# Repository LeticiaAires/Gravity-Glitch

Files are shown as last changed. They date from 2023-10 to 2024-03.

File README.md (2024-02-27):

# Gravity Glitch



## Introduction

Welcome to Gravity Glitch, an innovative project created by 7th-semester engineering students from École Nationale Supérieure de l'Électronique et de ses Applications (ENSEA). This project serves as a platform for hands-on learning in practical electronics, software development, project management, and teamwork.

## Project Objective

Our primary goal is to develop an exciting game inspired by the popular Flappy Bird game, with a unique twist – an innovative controller. We've integrated an infrared sensor into the game, which measures the distance between the player's hand and the sensor. This inventive controller allows players to guide "Flappy" through the game, helping it navigate obstacles and accumulate points.

## Getting Started

To get started with the project, follow these steps:

1. Clone the repository to your local machine:

   ```bash
   git clone https://github.com/LeticiaAires/Gravity-Glitch.git
   ```

2. Ensure you have the required dependencies installed.

   [VSCode](https://code.visualstudio.com/download)
 
   [Python]( https://www.python.org/downloads/)
 
   [PIP](https://bootstrap.pypa.io/get-pip.py)

3. How to play ?
   
   - Run the "main.py" file 
   
   - Click on the "Play" button to choose your pseudo and choose your game mode !

4. To launch the game without installing all modules and packages on your machine, create a virtual environment.

   - Create the environment 'my_env' inside the project directory :
     
      ```bash
      python -m venv my_environment
      ```

   - Activate the environment :
     
      ```bash
      my_environment/bin/activate
      ```

   - Install the required dependencies :
   
      ```bash
      pip install -r requirements.txt
      ```

   - Run the Game.py file and play !

   - Deactivate the environment :
     
      ```bash
      deactivate
      ```

## Features

- Flappy Bird-inspired gameplay with a unique controller.
- Innovative use of an infrared sensor for hand tracking.
- Challenging obstacles and addictive gameplay.
- Project designed and implemented by talented engineering students.

## Documentation
Here is an explanation of the game's structure : 

The "main.py" file is the file to run to start the Game. Then, we come across a window called "MainMenu" displaying the menu of the game (with the settings, play, quit, credits and rules buttons). From there, we can : 
- go to the settings/rules/credits windows who are self explanatory
- quit the game
- go to the play window
  
If you choose to do the later, then you will come across a first window asking for your name (to associate your score with your pseudo). From there you can either go back to the menu or continue and go choose your game mode (History mode or alternative = a more complex version of the flappy bird).
After that, by clicking on continue and pressing the space bar, you can start playing !
You have a "pause" button in the bottom left corner where you can go to the settings, see the best scores, restart, resume or quit the game. 
  
For more detailed information about the project, you can refer to the code itself. We have included comprehensive comments and documentation within the codebase to help you understand how everything works.

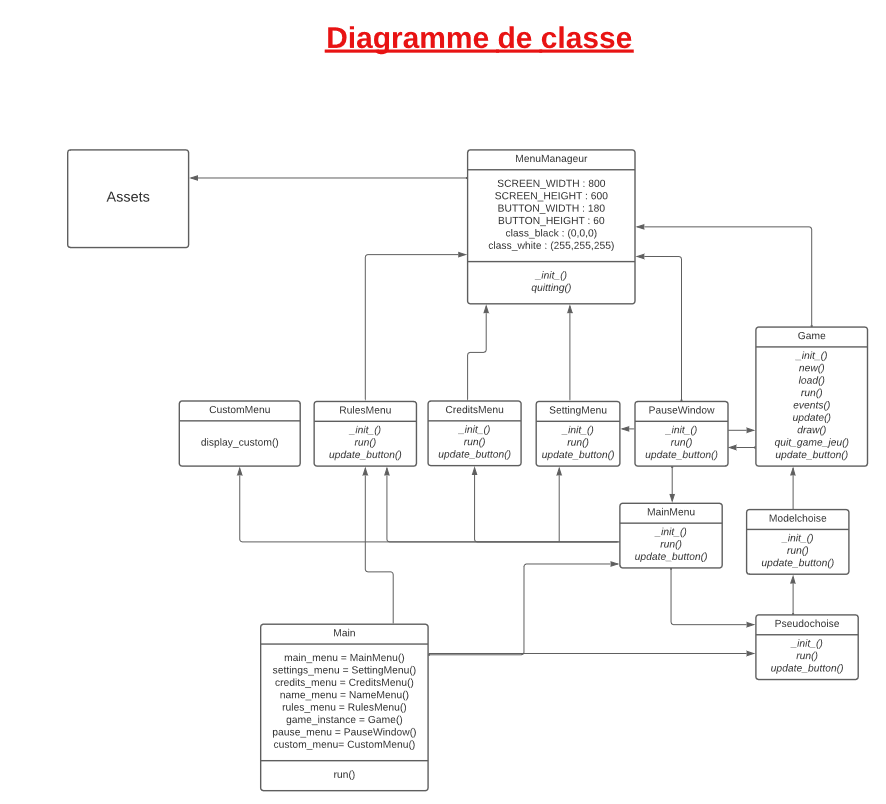
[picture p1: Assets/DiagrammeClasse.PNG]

## License

This project is licensed under the [MIT License](LICENSE.md).

## Acknowledgments

We would like to express our gratitude to our instructors, mentors, and everyone who supported us throughout this project. Your guidance and encouragement were invaluable in making this project a reality.

## Collaborators

<table>
  <tr>
    <td align="center">
      <a href="#">
        Foto Anthony
        <sub>
          <b>Anthony </b>
          </p>AnthonyDelille01     
        </sub>
      </a>
    </td>
    <td align="center">
      <a href="#">
        Foto Cassandre<br>
        <sub>
          <b>Cassandre   </b>
          </p>CassandreChandelier   
        </sub>
      </a>
      <td align="center">
      <a href="#">
        Foto Douay<br>
        <sub>
          <b>Douay Nicolas</b>
          </p>DBXYD
        </sub>
      </a>
    </td>
    <td align="center">
      <a href="#">
        Foto Letícia Aires<br>
        <sub>
          <b>Letícia Aires</b>
          </p>LeticiaAires
        </sub>
      </a>
    </td>
    <td align="center">
      <a href="#">
        Foto Mael<br>
        <sub>
          <b>Mael Doublet</b>
          </p>MaelDoublet
        </sub>
      </a>
      <td align="center">
      <a href="#">
        Foto Mantou<br>
        <sub>
          <b>Mantou</b>
          </p>Mansko09
        </sub>
      </a>
<td align="center">
      <a href="#">
        Foto Mathieu<br>
        <sub>
          <b>Mathieu Daubercies</b>
          </p>MathieuDaubercies
        </sub>
      </a>
      <td align="center">
      <a href="#">
        <br>
        <sub>
          <b>Solène</b>
          </p>salom0701
        </sub>
      </a>
      <td align="center">
      <a href="#">
        Foto Romain<br>
        <sub>
          <b>Romain</b>
          </p>Romain04G
        </sub>
      </a>
      <td align="center">
      <a href="#">
        Foto Zineb<br>
        <sub>
          <b>Zineb</b>
          </p>Ninevv
        </sub>
      </a>

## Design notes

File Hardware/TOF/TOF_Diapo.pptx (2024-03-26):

## TOF Process

Communicating with a TOF sensor

## Steps for TOF ranging

I. Pin configuration
II. USART communication
III. TOF ranging
IV. Getting the distance

## Pin configuration

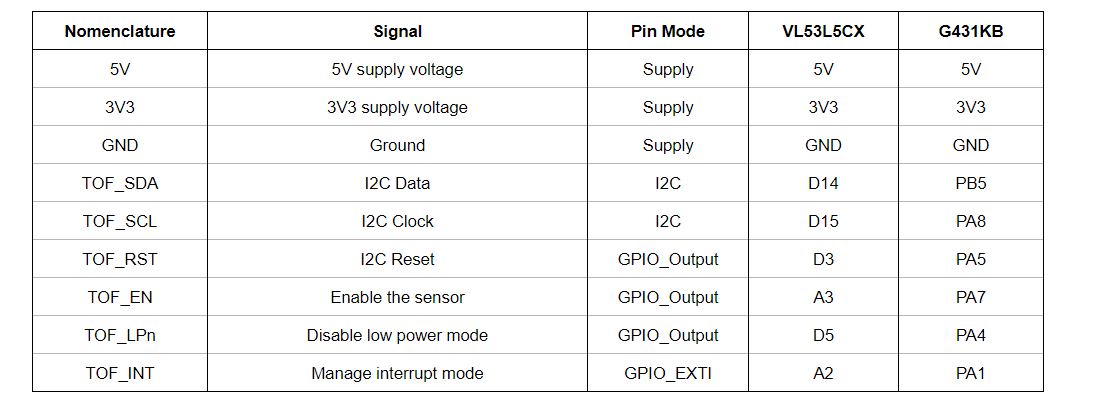
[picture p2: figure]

## Pin configuration

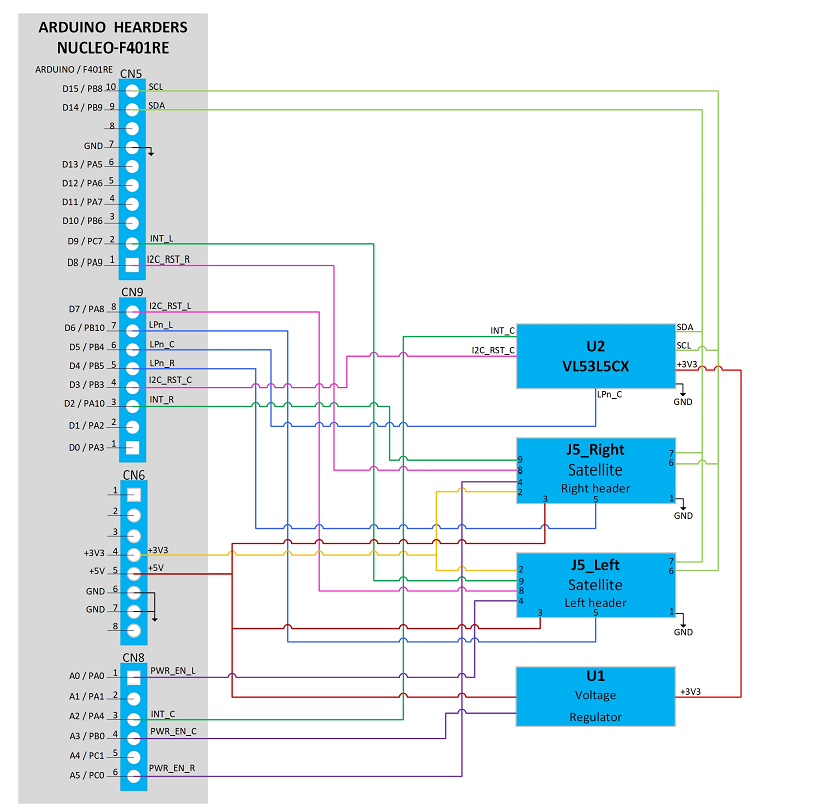
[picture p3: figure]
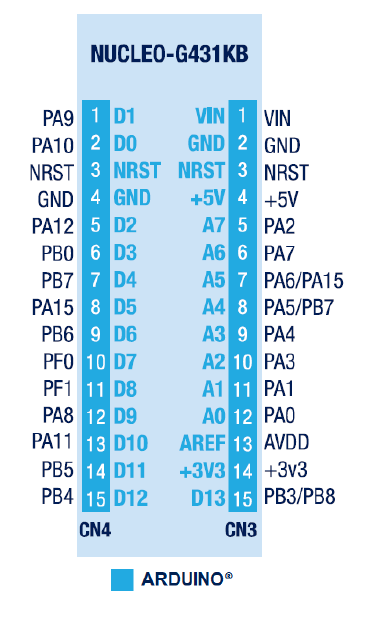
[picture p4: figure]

## Checking pin configuration

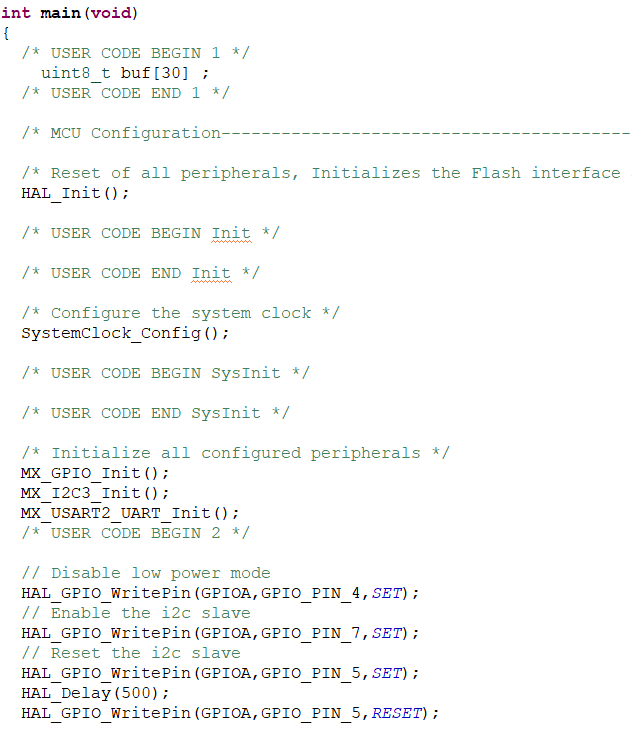
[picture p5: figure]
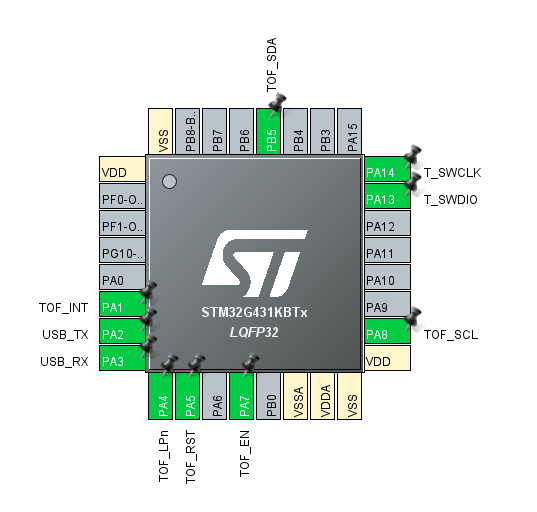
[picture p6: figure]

## Checking pin configuration

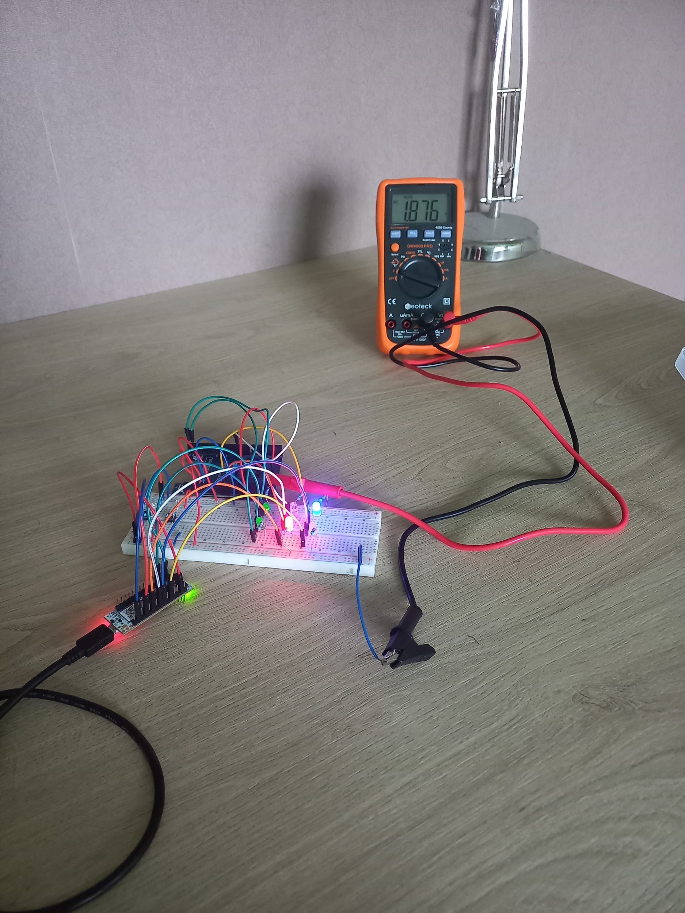
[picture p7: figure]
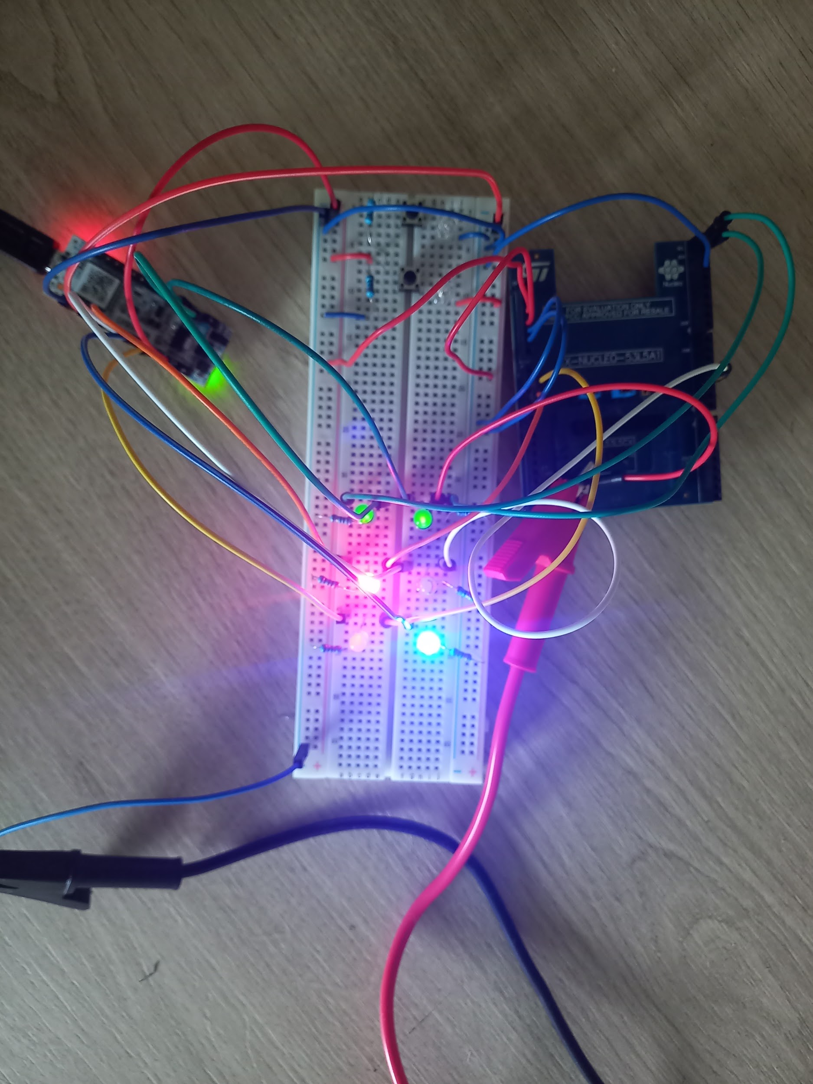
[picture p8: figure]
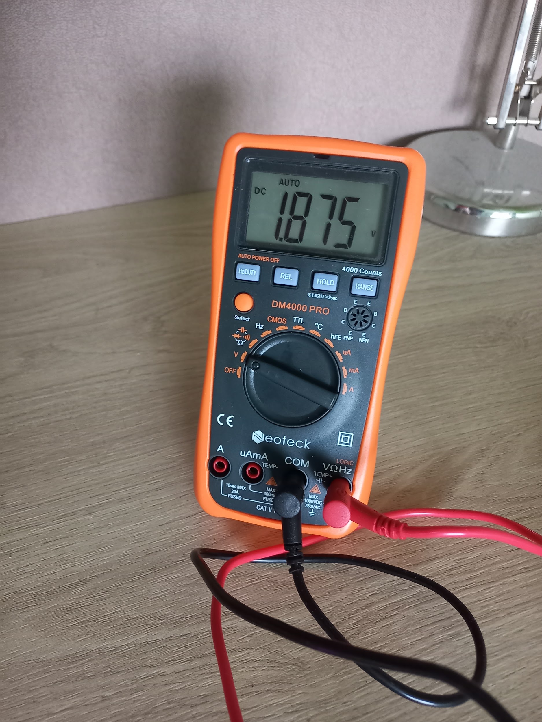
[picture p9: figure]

## USART communication

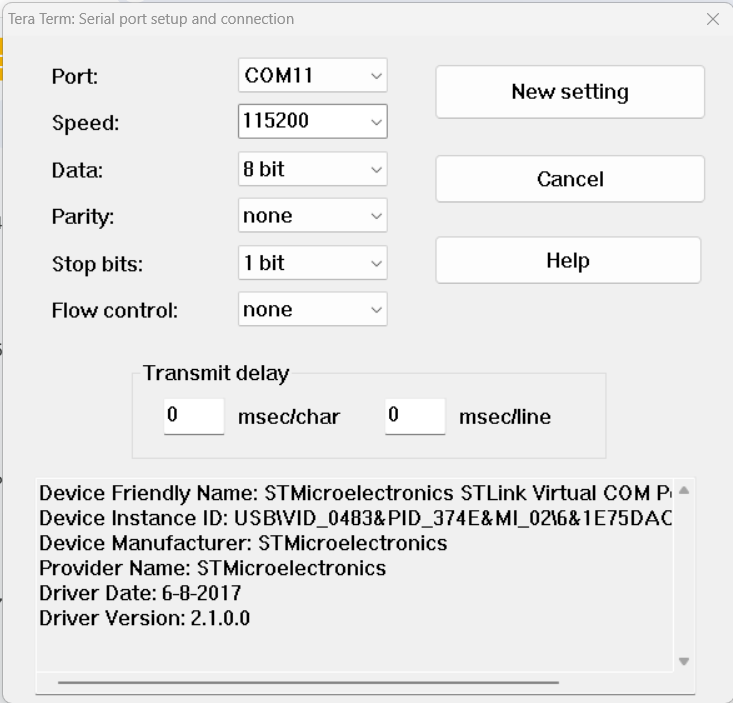
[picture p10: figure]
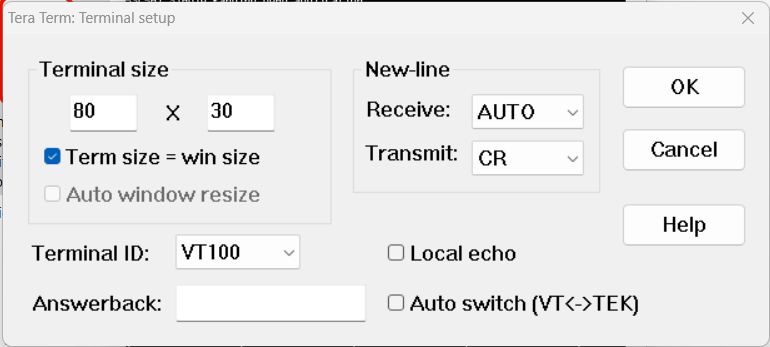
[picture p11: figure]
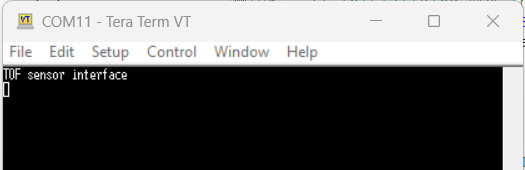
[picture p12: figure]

## USART communication

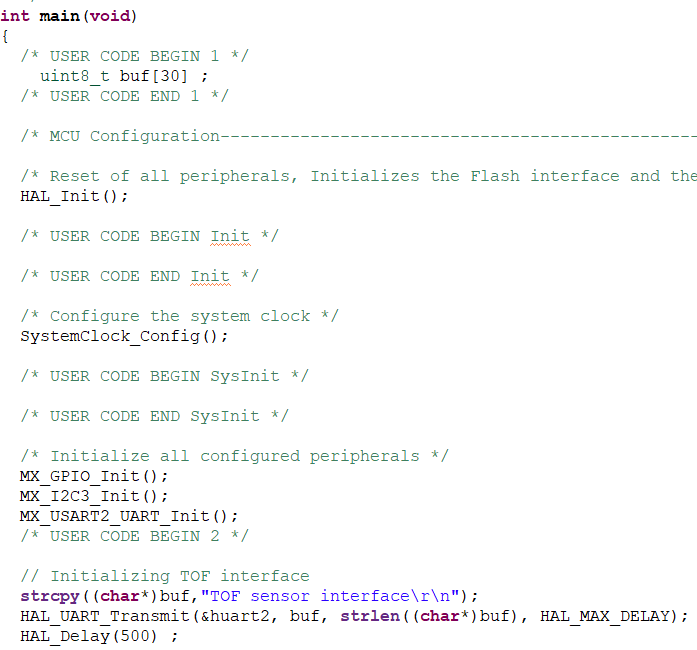
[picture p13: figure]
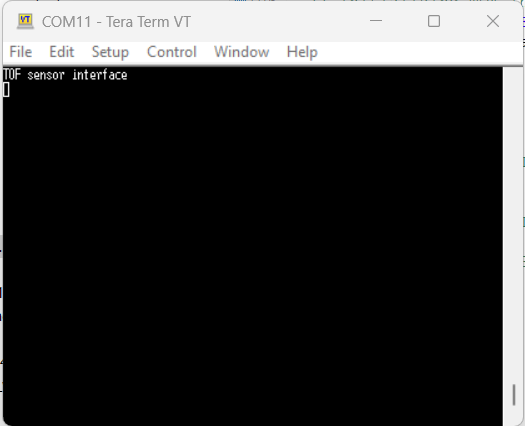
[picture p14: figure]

## TOF ranging

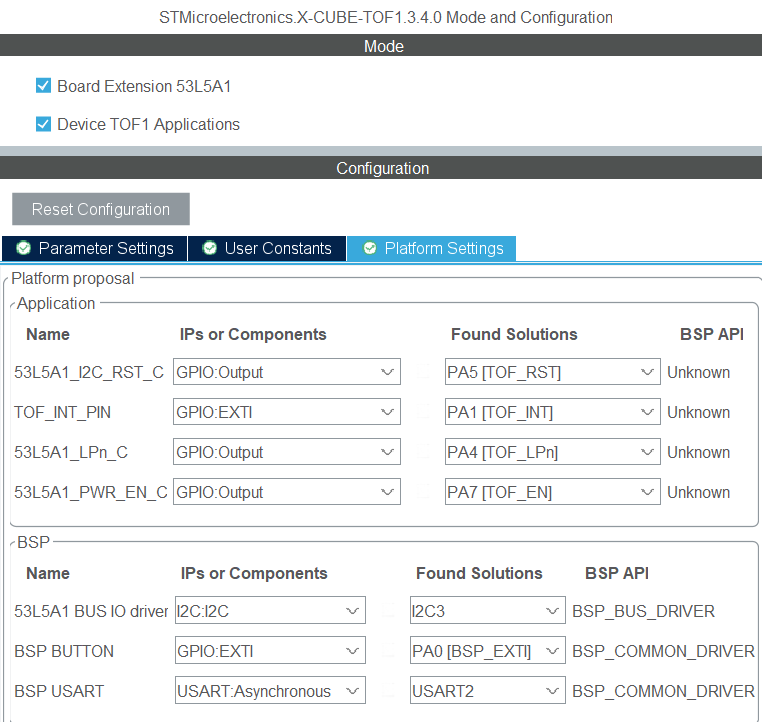
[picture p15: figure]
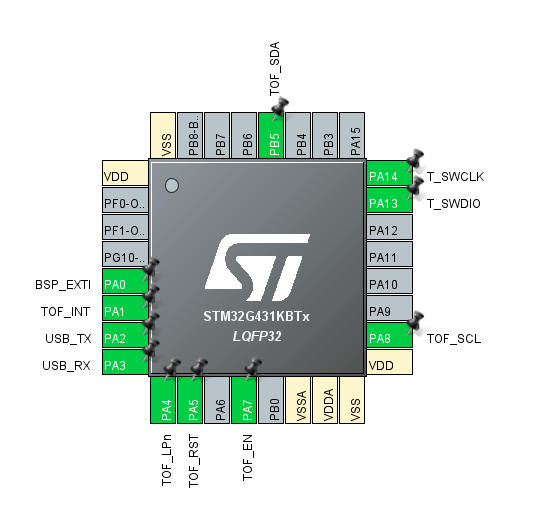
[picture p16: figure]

## TOF ranging

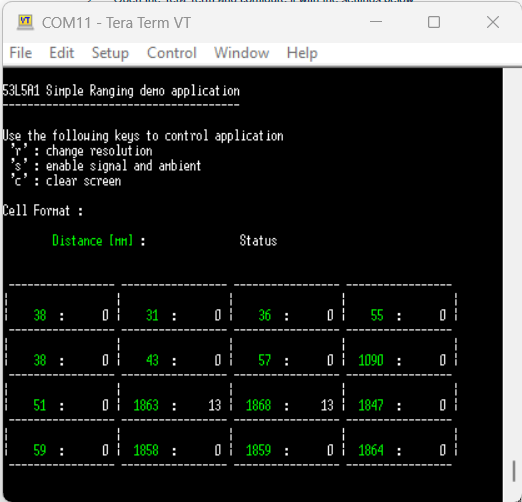
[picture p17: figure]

## Getting the distance

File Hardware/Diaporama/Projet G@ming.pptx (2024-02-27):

## Projet ~~G@ming~~ Gaming

Anthony Delille, Mathieu Daubercies, Nicolas Douay, Mael Doublet, Romain Gaillard

## Objectifs

- Faire un schéma global du système
- Connecter le TOF et la STM32
- Commencer le KiCad
- Se renseigner sur le bluetooth

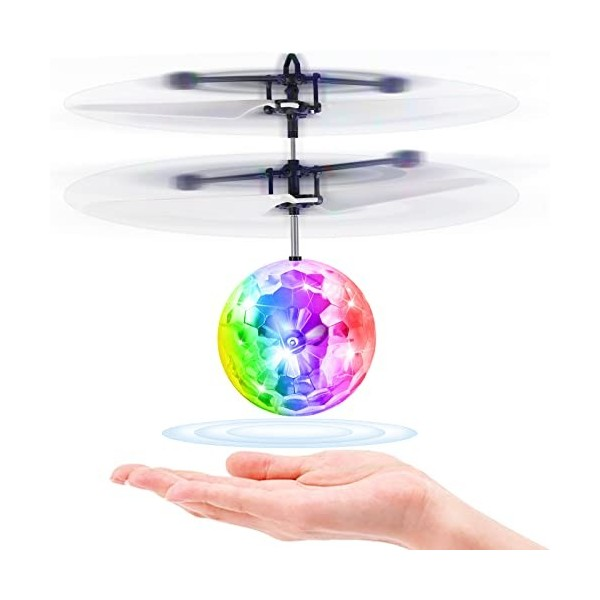
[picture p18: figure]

## Architecture générale

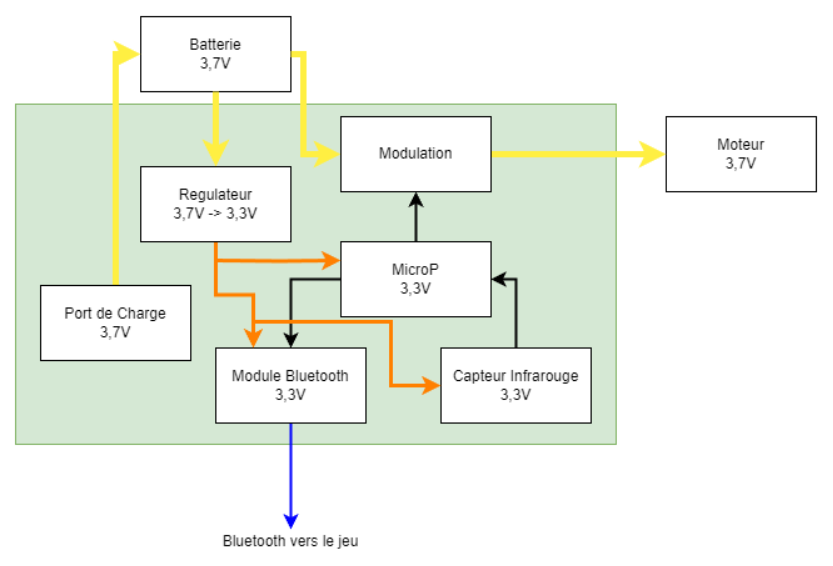
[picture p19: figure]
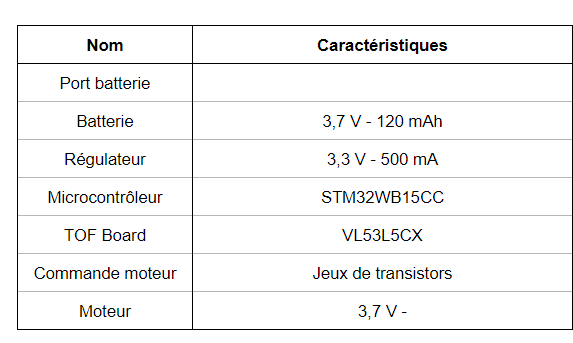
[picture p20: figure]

## Communication avec le TOF

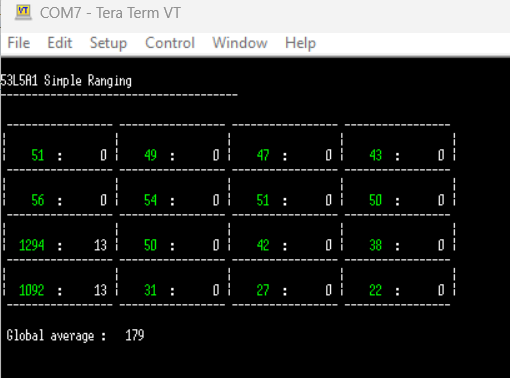
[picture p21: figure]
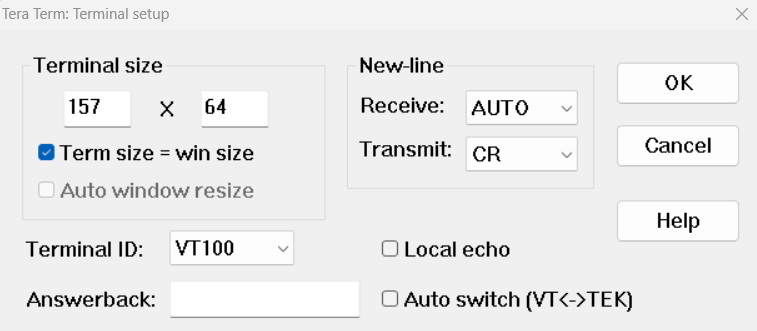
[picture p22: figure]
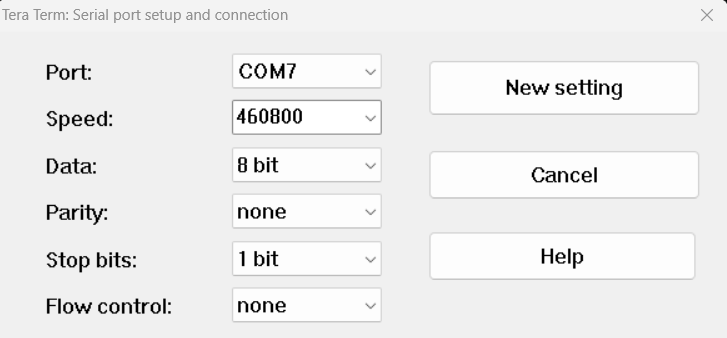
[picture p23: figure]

## Changement de carte

- Adaptation de la configuration de pins
- Création d’un nouveau projet :
  - Configuration IOC avec WB15CC
  - Erreurs dans la compilation du code

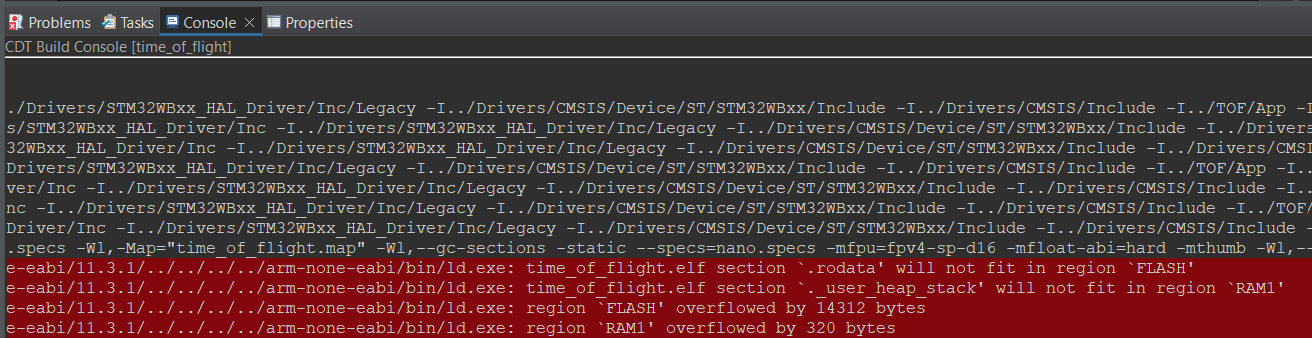
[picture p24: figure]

## Schematic du TOF

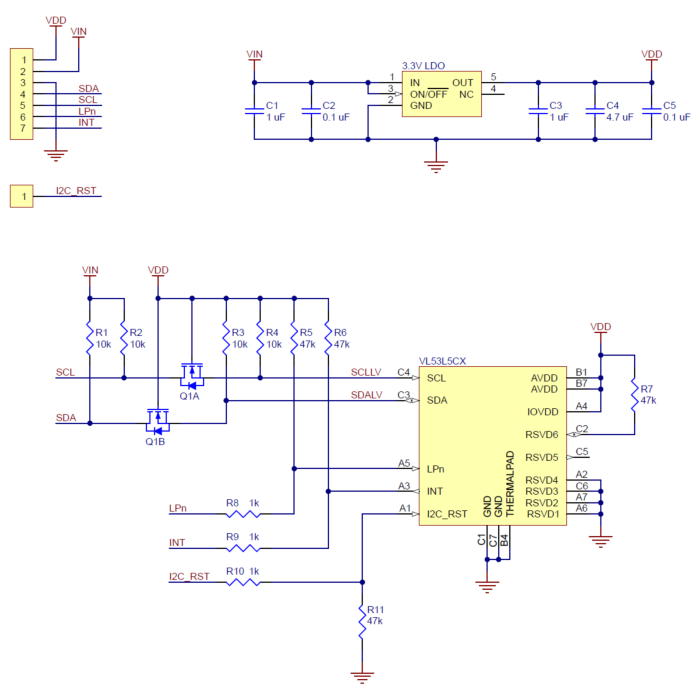
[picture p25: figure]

Régulateur de tension


TOF

## Schematic du TOF

VDD : 3.3 V
Régulateur de tension : VIN entre 2.8 V et 5.5 V


## Première piste pour le bluetooth

- Module
  - HC-05 / HC-06 : MAIS peut-être un peu grand: 35*16*12 mm
    - HC-05 : très courant / émetteur ou récepteur / fréquence d’émission réglable / fonctions AT
    - HC-06 : variante plus simple d’utilisation du HC-05 / fréquence d’émission réglable NON REGLABLE
    - blueNRG : de STM32 / beaucoup de docs / pas les fonctions AT
- Juste envoyer des données à l’ordinateur
  - configurer en mode émetteur
- Fonctions AT
  - permettent de paramétrer les caractéristiques du réseaux bluetooth: vitesse / nom / …
  - PAS TOUS les modules sont compatibles

## Et après ??

- Continuer la partie bluetooth
  - Choisir quelle module utilisé
  - trouver du code
- Régler le problème du changement de carte du TOF
- Continuer le Kicad

## Annexes

## Affichage de la moyenne


## Code de la moyenne


## Mémo pins TOF


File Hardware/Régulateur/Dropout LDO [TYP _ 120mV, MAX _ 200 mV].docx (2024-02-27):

Chute maximale de tension de 200 mV lorsque la tension de sortie est 100 mV en dessous de sa valeur minimale.

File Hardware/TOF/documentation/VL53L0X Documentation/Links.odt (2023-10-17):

LINKS

Programming I2C with STM32

https://wiki.st.com/stm32mcu/wiki/Getting_started_with_I2C

Programming I2C with Nucleo board and Time-of-Flight sensor :

https://www.youtube.com/watch?v=cvmQNTVJrzs

I2C in driver C :

https://www.youtube.com/watch?v=yZGWpDTbjdw

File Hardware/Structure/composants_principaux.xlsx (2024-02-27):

Composants principaux
Nom | Caractéristiques | Disponibilité | Datasheet
Port batterie |  | Fourni par le drône
Batterie | 3,7 V - 120 mAh | Fourni par le drône
Régulateur | 3,3 V - 500 mA | Commandé via Patricia | https://www.ti.com/lit/ds/symlink/lp3990.pdf?HQS=dis-mous-null-mousermode-dsf-pf-null-wwe&ts=1699970352925
Microcontrôleur | STM32WB15CC
TOF Board | VL53L5CX
Commande moteur | Jeux de transistors
Moteur | 3,7 V - | Fourni par le drône

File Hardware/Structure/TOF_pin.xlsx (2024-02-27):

TOF pin configuration
Nomenclature | Signal | Connecteur | Pin
VDD | 2,8 V out | not connected | not connected
VIN | 3,3 V in | CN6 | 3V3
GND | GND | GND | GND
SDA | I2C serial datas | CN5 | D14
SDL | I2C serial clock | CN5 | D15
XSHUT | Not enable pin | not connected | not connected
GPIO1 | Interrupt output pin | not connected | not connected

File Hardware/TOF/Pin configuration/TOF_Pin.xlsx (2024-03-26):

TOF pin configuration
Nomenclature | Signal | Pin Mode | VL53L5CX | G431KB
5V | 5V supply voltage | Supply | 5V | 5V
3V3 | 3V3 supply voltage | Supply | 3V3 | 3V3
GND | Ground | Supply | GND | GND
TOF_SDA | I2C Data | I2C | D14 | PB5
TOF_SCL | I2C Clock | I2C | D15 | PA8
TOF_RST | I2C Reset | GPIO_Output | D3 | PA5
TOF_EN | Enable the sensor | GPIO_Output | A3 | PA7
TOF_LPn | Disable low power mode | GPIO_Output | D5 | PA4
TOF_INT | Manage interrupt mode | GPIO_EXTI | A2 | PA1

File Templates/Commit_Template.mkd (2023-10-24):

## Commit

Commiting is the act of inserting your code adjustments into the main code, in which everyone is working.
In order for us to better understand each other's commits, they must be brief, descriptive and have a pattern.

### Principles:

#### Atomic commits
Commits must always be small and significative, in order for them to represent only one functionality.
This allows us to better track each code alteration, as well as have more knowledge about the code.

### Format:
```
<type>(#issue number): description
```

#### Avaiable Types:

[***Emoji Markdown List***](https://gist.github.com/rxaviers/7360908)

- :rocket: front-end code ```:rocket:```
- :floppy_disk: back-end code ```:floppy_disk:```
- :repeat: code alteration ```:repeat:```
- :cool: code structure upturn ```:cool:```
- :racehorse: functioning upturn ```:racehorse:```
- :x:  memory leaks solving```:x:```
- :pencil: documentation writting ```:pencil:```
- :bug: bug solving ```:bug:```
- :fire: removing code from archives ```:fire:```
- :green_heart: fixing continuous integration problems ```:green_heart:```
- :white_check_mark: adding tests ```:white_check_mark:```
- :lock: dealing with safety ```:lock:```
- :arrow_up: dependency upgrade ```:arrow_up:```
- :arrow_down: dependency downgrade ```:arrow_down:```

#### Matter:
- Must have up to 50 characters
- Must not have capital letters

*Commit example:*
```
git commit -m ":bulb:(#02): initial page button"
```
## Version History

| Date | Version | Description | Author |
| :---: | :----: | :---: | :---: |
| 20/10/2023 |  0.1 | Creating commit policy | Letícia Aires|

## Referências

DARTORA, João. Tudo o que você precisa saber sobre commits semânticos. *Ilegra*. Disponível em: <https://ilegra.com/blog/tudo-o-que-voce-precisa-saber-sobre-commits-semanticos/>. Acesso em: 09 de ago. de 2021.

Políticas de Commit. Disponível em: <https://fga-eps-mds.github.io/2020.1-Grupo6/policies/commits/>. Acesso em: 09 de ago. de 2021

Políticas de Commit. Disponível em: <https://github.com/fga-eps-mds/2021.1-AlligaBot/blob/main/docs/_posts/2021-08-18-commits.md>. Acesso em: 14 de fev. de 2022


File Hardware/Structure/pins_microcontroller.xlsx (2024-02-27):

Pins microcontroller
Ref | Nomenclature | Type | Structure | Functions | Attribution
 | VBAT | S | - | -
 | VSS | S | - | - | VSS
 | PC14 | I/O | FT | OSC32_IN, CM4_EVENTOUT
 | PC15 | I/O | FT | OSC32_OUT, CM4_EVENTOUT
 | PB10 | I/O | FT | TSC_G3_IO2, CM4_EVENTOUT
 | PH3 | I/O | FT | LSCO, CM4_EVENTOUT
 | PB8 | I/O | FT_f | TIM1_CH2N, I2C1_SCL, TSC_G7_IO3, CM4_EVENTOUT | TOF_I2C_SCL
 | VSS | S | - | - | VSS
 | VDD | S | - | -
 | PB9 | I/O | FT_f | TIM1_CH3N, I2C1_SDA, TSC_G7_IO4, CM4_EVENTOUT | TOF_I2C_SDA
 | VSS | S | - | - | VSS
 | PB11 | I/O | NRST | -
 | VDDA | S | - | -
 | PA0 | I/O | FT_a | TIM2_CH1, COMP1_OUT, TIM2_ETR, CM4_EVENTOUT, COMP1_INM, ADC1_IN5, RTC_TAMP2/WKUP1
 | PA1 | I/O | FT_a | TIM2_CH2, I2C1_SMBA, SPI1_SCK, CM4_EVENTOUT, COMP1_INP, ADC1_IN6
 | PA2 | I/O | FT_a | LSCO(2), TIM2_CH3, LPUART1_TX, CM4_EVENTOUT, ADC1_IN7, WKUP4
 | PA3 | I/O | FT_a | TIM2_CH4, LPUART1_RX, CM4_EVENTOUT, ADC1_IN8
 | PB12 | I/O | FT | TIM2_CH2, TSC_G1_IO1, CM4_EVENTOUT
 | VSS | S | - | - | VSS
 | PA4 | I/O | FT_a | SPI1_NSS(boot), LPTIM2_OUT, CM4_EVENTOUT, COMP1_INM, ADC1_IN9
 | PA5 | I/O | FT_a | TIM2_CH1, TIM2_ETR, SPI1_MOSI, SPI1_SCK(boot), LPTIM2_ETR, CM4_EVENTOUT, COMP1_INM, ADC1_IN10
 | PA6 | I/O | FT_a | TIM1_BKIN, SPI1_MISO(boot), LPUART1_CTS, CM4_EVENTOUT, ADC1_IN11
 | PA7 | I/O | FT_a | TIM1_CH1N, SPI1_MOSI(boot), CM4_EVENTOUT, ADC1_IN2
 | PA8 | I/O | FT_a | MCO, TIM1_CH1, USART1_CK, LPTIM2_OUT, CM4_EVENTOUT, ADC1_IN3
 | PA9 | I/O | FT_a | TIM1_CH2, I2C1_SCL, USART1_TX(boot), CM4_EVENTOUT, COMP1_INM, ADC1_IN4
 | PB2 | I/O | FT_a | RTC_OUT, LPTIM1_OUT, SPI1_NSS, CM4_EVENTOUT, COMP1_INP
 | VSS | S | - | - | VSS
 | VDD | S | - | -
 | VSSRF | S | - | -
 | RF1 | I/O | RF | -
 | VSSRF | S | - | -
 | VSSRF | S | - | -
 | VSSRF | S | - | -
 | VDDRF | S | - | -
 | OSC_OUT | O | RF | -
 | OSC_IN | I | RF | -
 | AT0 | I/O | RF | -
 | AT1 | I/O | RF | -
 | PB0 | I/O | TT | RF_TX_MOD_EXT_PA, COMP1_OUT, CM4_EVENTOUT
 | PB1 | I/O | TT | LPUART1_RTS_DE, LPTIM2_IN1, CM4_EVENTOUT
 | VDD | S | - | -
 | PB13 | I/O | FT | TIM2_CH3, TSC_G1_IO2, CM4_EVENTOUT
 | PE4 | I/O | FT | CM4_EVENTOUT
 | VFBSMPS
 | VFBSMPS
 | VLXSMPS
 | VDDSMPS
 | VDD
 | PB14
 | PB15
 | PA10
 | PA11
 | PA12
 | PA13
 | VDD
 | PC1
 | PA14
 | PA15
 | PB3
 | PB4
 | PB5
 | VDD

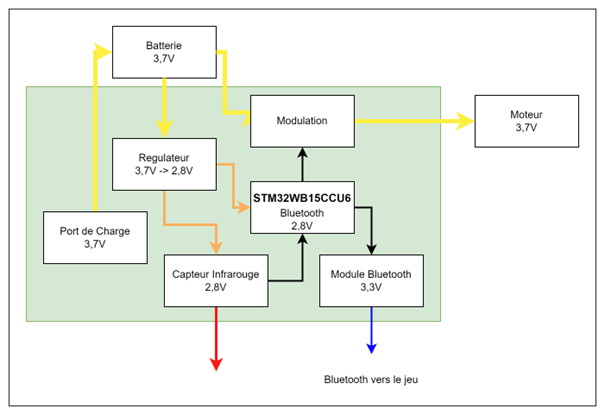
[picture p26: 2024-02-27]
Hardware/Structure/Structure.png

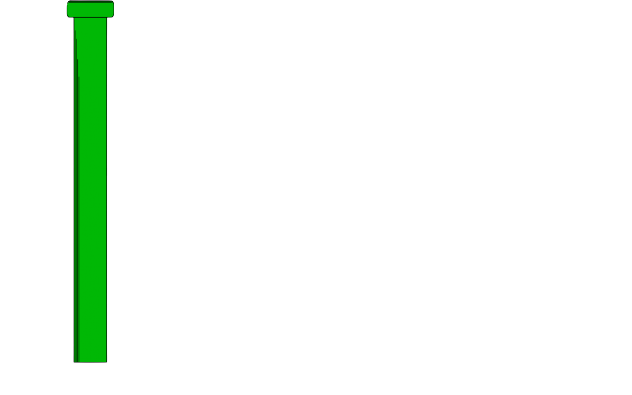
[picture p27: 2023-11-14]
Assets/tuyau_final.png

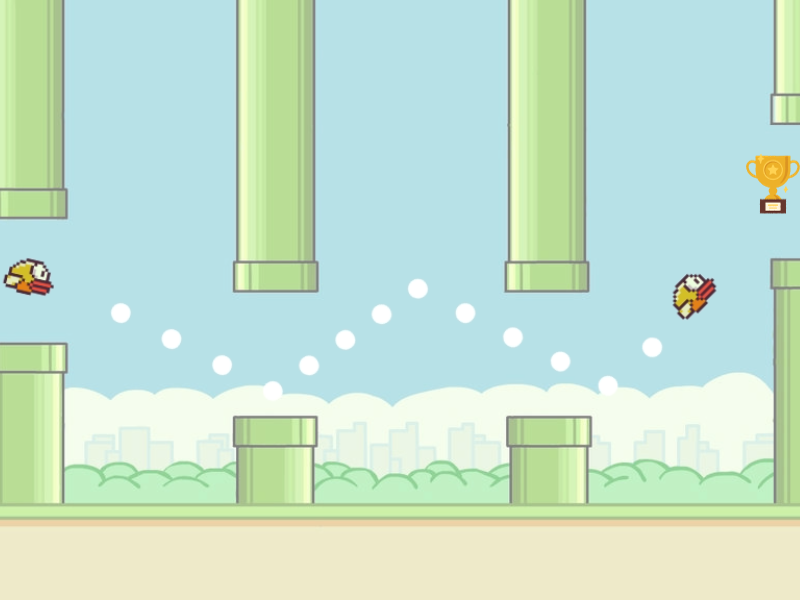
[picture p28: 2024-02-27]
Assets/pauseWindow_screen2.png

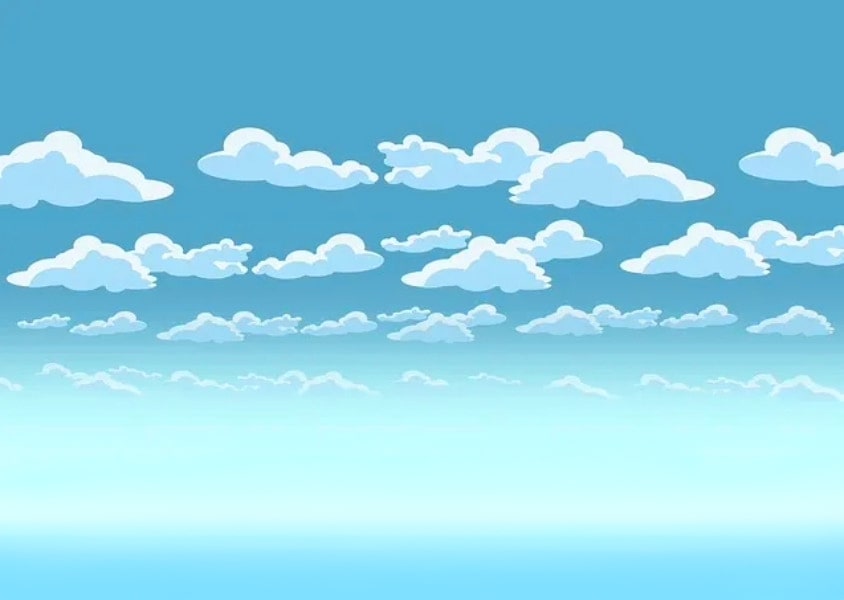
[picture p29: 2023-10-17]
Assets/background2.jpg

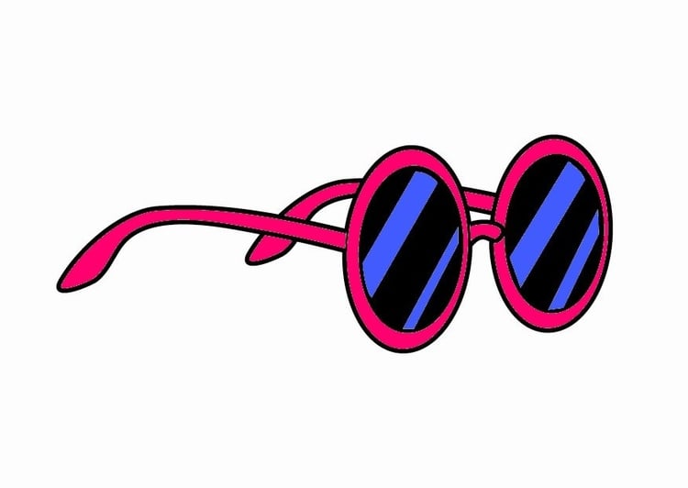
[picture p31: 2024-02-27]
Assets/lunettes-de-soleil.jpg

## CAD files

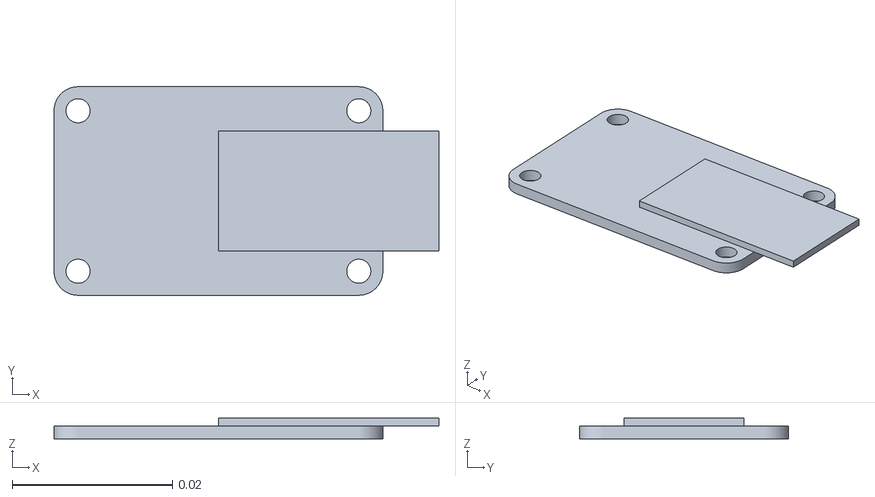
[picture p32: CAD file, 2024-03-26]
Hardware/Supports 3D/Manette_PCB.stl
0.048 x 0.026 x 0.0026

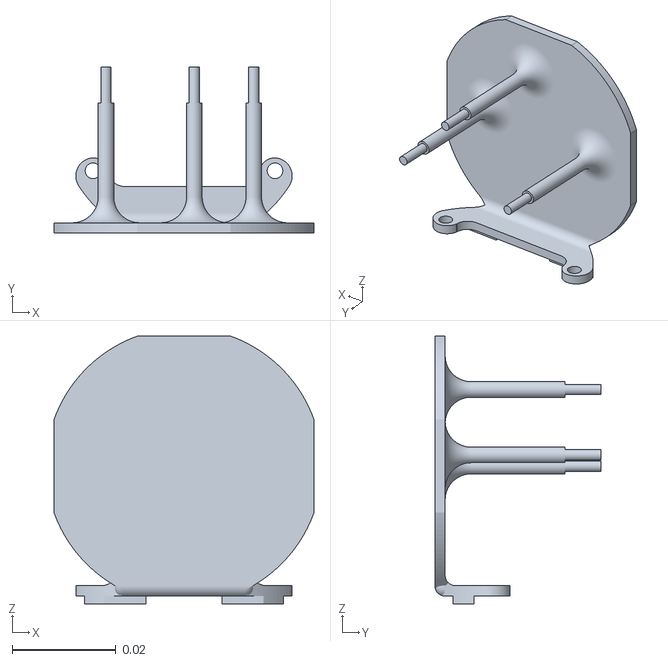
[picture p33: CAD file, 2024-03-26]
Hardware/Supports 3D/Manette-Moteur.stl
0.05 x 0.032 x 0.0515

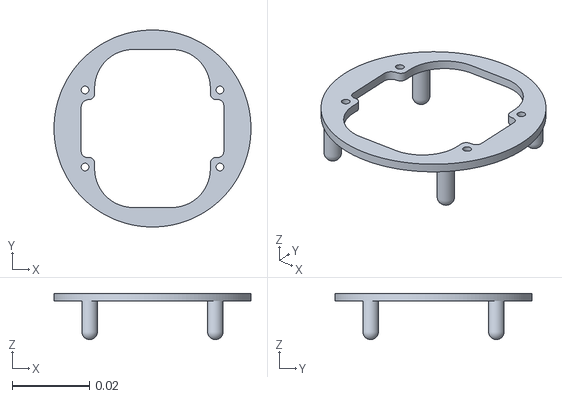
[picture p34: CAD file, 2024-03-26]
Hardware/Supports 3D/Manette_Base.stl
0.0511 x 0.0511 x 0.012

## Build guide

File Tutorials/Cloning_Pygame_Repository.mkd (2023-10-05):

# How to Make your Pygame Project Work
## Introduction
This is a quick step by step guide on how to install pygame on your computer so we can start developing our project!
## Requirements
* Install [VSCode](https://code.visualstudio.com/download) 
* Install [Python]( https://www.python.org/downloads/)
  * Add Python to PATH in the installation
  * Check in the command prompt if it was installed correctly python --version
* Install [PIP](https://bootstrap.pypa.io/get-pip.py)
  * Usually, it comes with the Python installation itself, so check if you don't have it already
  * Check in the command prompt pip --version
* Install [Gitbash](https://gitforwindows.org/)
  * To check if it was indeed installed correctly, type out on your cmd git --version 
## Step 1
Go to the initial page of the repository and copy it's HTTPS link

## Step 2
Now go inside your computer folders and press the right mouse button where you want you repository to be
Next, choose the option "Open Git Bash here" 

## Step 3
A small window will open in which you will have to type out the following code: git clone 'link of you repository here'

The git software will make a clone of the repository into you chosen folder
## Step 4
Open you VSCode and go to File>Open Folder>Chosen repository folder of yours

## Step 5
Great! Now we only have to install the Pygame library into your VSCode project
Go to your project's terminal and type: pip install pygame

As you can see, mine was already installed
## Step 6
Now run your code to test if everything is working


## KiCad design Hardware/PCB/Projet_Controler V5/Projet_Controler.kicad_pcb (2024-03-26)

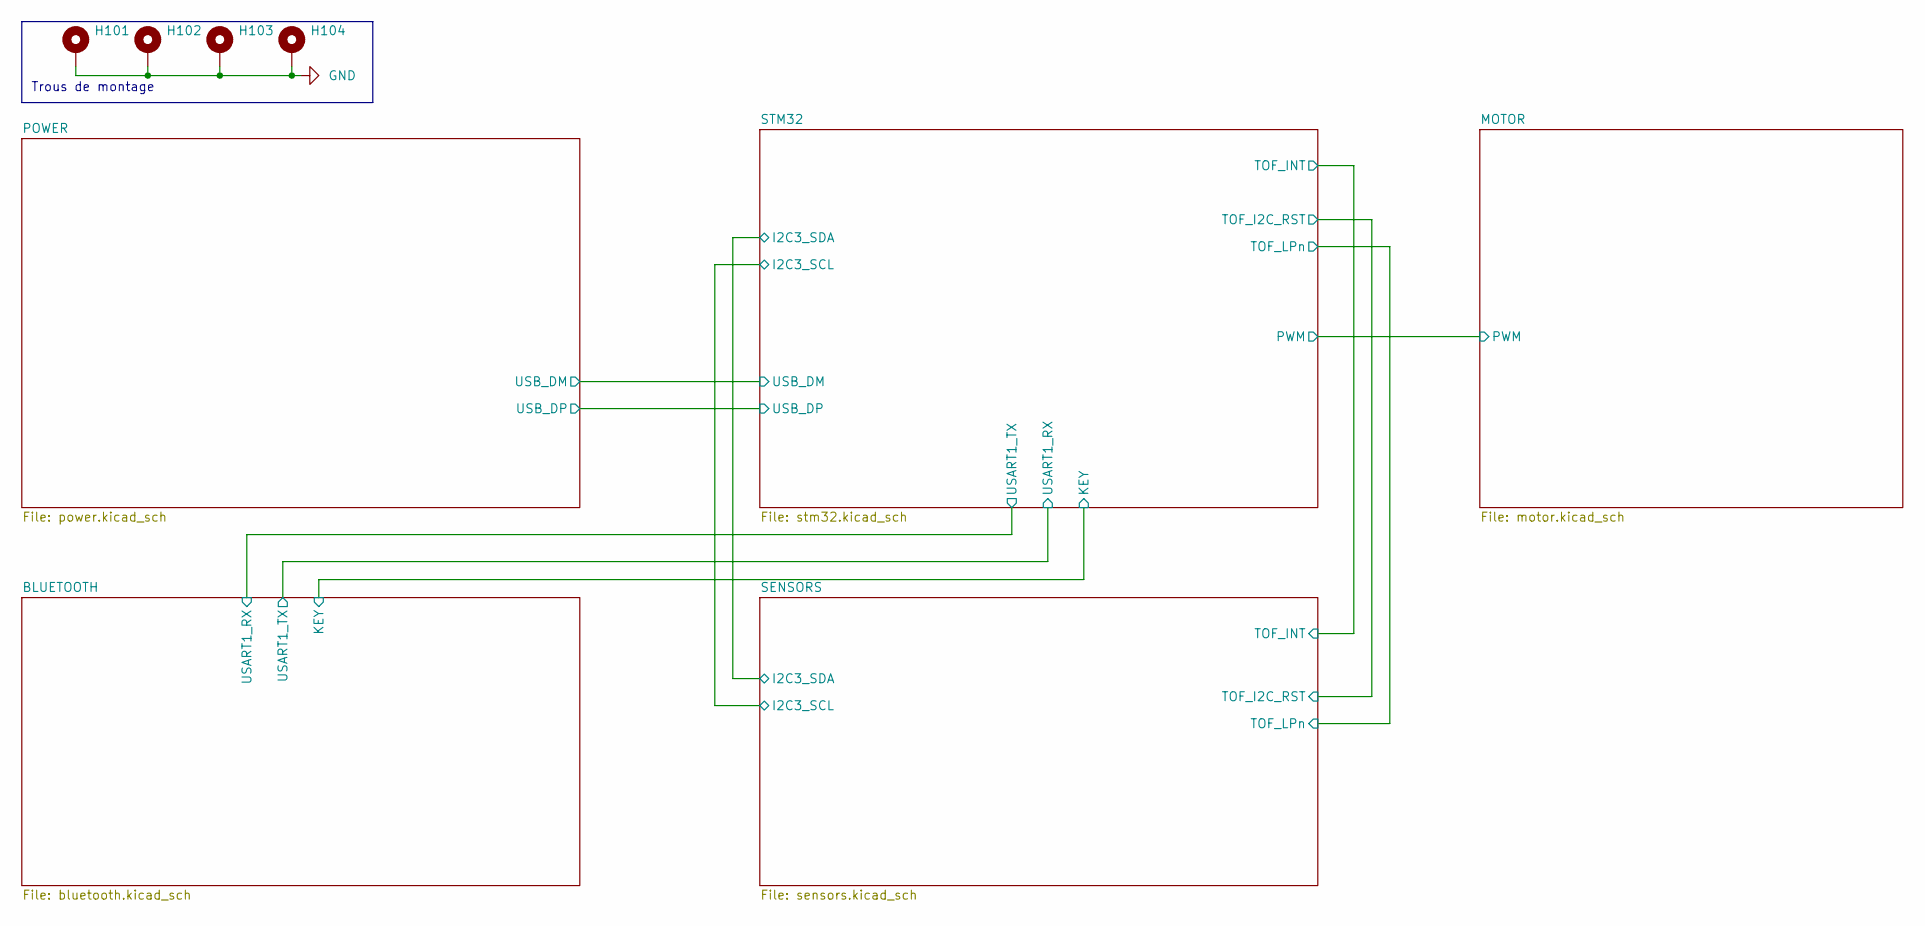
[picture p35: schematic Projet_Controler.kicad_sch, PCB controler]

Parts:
H101, H102, H103, H104: MountingHole_Pad; MountingHole_2.7mm_M2.5_DIN965_Pad

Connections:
GND: H101.1, H102.1, H103.1, H104.1; also elsewhere on the board

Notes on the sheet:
Trous de montage

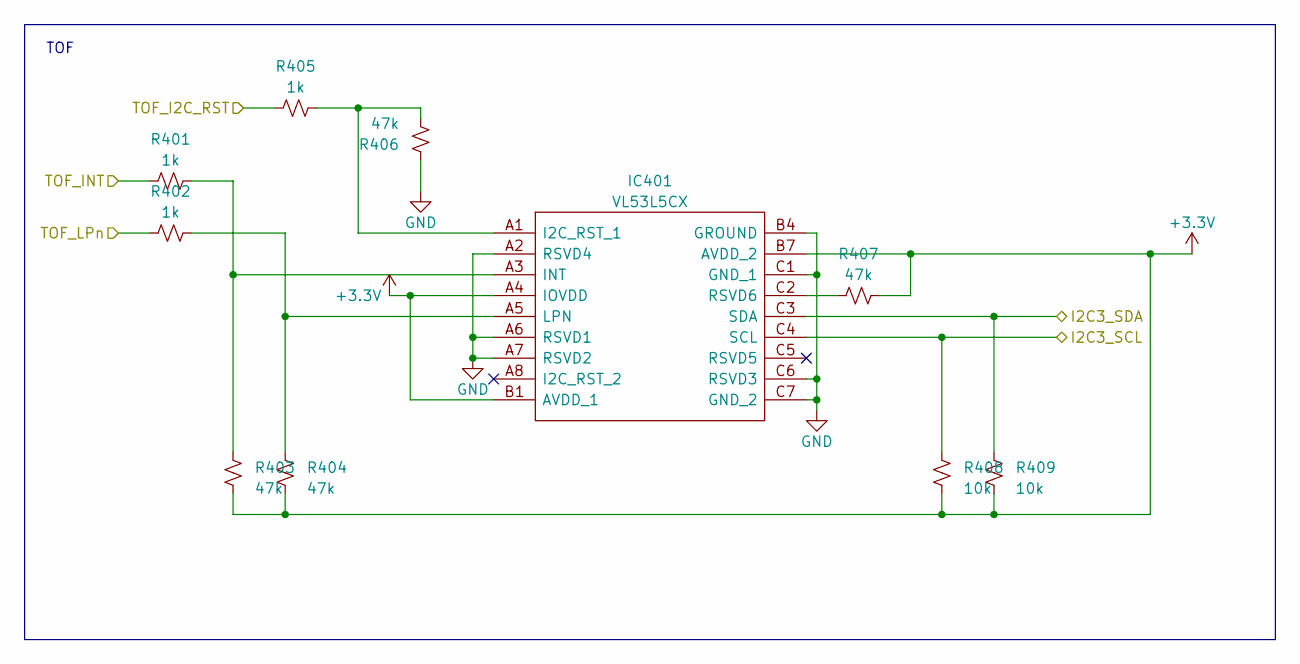
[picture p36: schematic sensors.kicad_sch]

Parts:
IC401: VL53L5CX; Manufacturer_Part_Number VL53L5CX
R401, R402, R405: 1k; R_0402_1005Metric
R403, R404, R406, R407: 47k; R_0402_1005Metric
R408, R409: 10k; R_0402_1005Metric

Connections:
+3.3V: IC401.A4 (IOVDD), IC401.B1 (AVDD_1), IC401.B7 (AVDD_2), R403.1, R404.1, R407.2, R408.1, R409.1; also elsewhere on the board
/SENSORS/I2C3_SCL: IC401.C4 (SCL), R408.2; also elsewhere on the board
/SENSORS/I2C3_SDA: IC401.C3 (SDA), R409.2; also elsewhere on the board
/SENSORS/TOF_I2C_RST: R405.2; also elsewhere on the board
/SENSORS/TOF_INT: R401.2; also elsewhere on the board
/SENSORS/TOF_LPn: R402.2; also elsewhere on the board
GND: IC401.A2 (RSVD4), IC401.A6 (RSVD1), IC401.A7 (RSVD2), IC401.B4 (GROUND), IC401.C1 (GND_1), IC401.C6 (RSVD3), IC401.C7 (GND_2), R406.2; also elsewhere on the board
unnamed 28: IC401.A1 (I2C_RST_1), R405.1, R406.1; also elsewhere on the board
unnamed 29: IC401.A3 (INT), R401.1, R403.2; also elsewhere on the board
unnamed 30: IC401.A5 (LPN), R402.1, R404.2; also elsewhere on the board
unnamed 31: IC401.C2 (RSVD6), R407.1; also elsewhere on the board

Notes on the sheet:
TOF

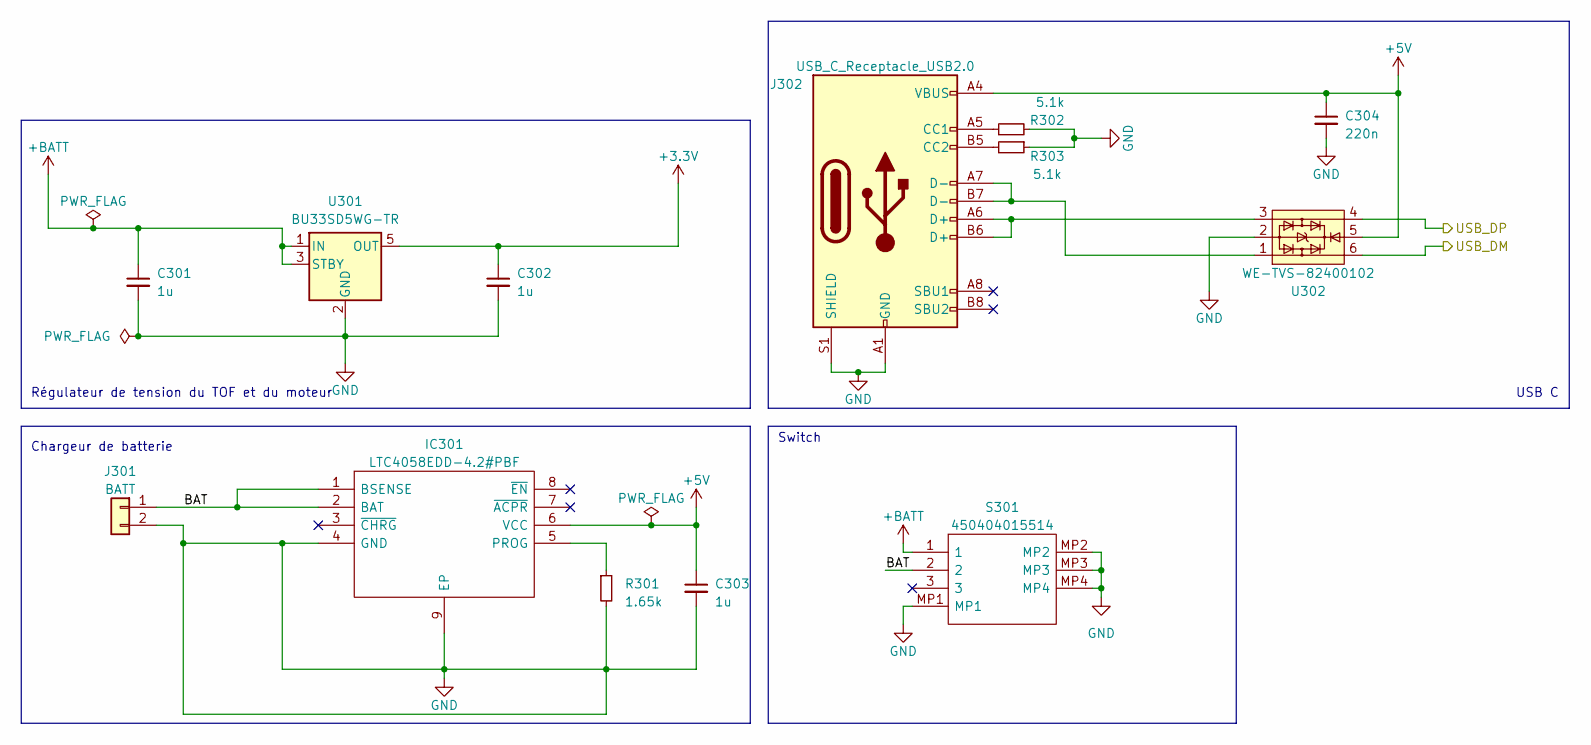
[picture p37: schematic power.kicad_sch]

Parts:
C301, C302, C303: 1u; C_0402_1005Metric
C304: 220n; C_0402_1005Metric
IC301: LTC4058EDD-4.2#PBF; DFN-8-1EP_3x3mm_P0.5mm_EP1.65x2.38mm_ThermalVias; Manufacturer_Part_Number LTC4058EDD-4.2#PBF; Mouser Part Number 584-C4058EDD-4.2PBF
J301: BATT; PinHeader_1x02_P1.27mm_Vertical
J302: USB_C_Receptacle_USB2.0; USB_C_Receptacle_HRO_TYPE-C-31-M-12
R301: 1.65k; R_0402_1005Metric
R302, R303: 5.1k; R_0402_1005Metric
S301: 450404015514; Manufacturer_Part_Number 450404015514; Mouser Part Number 710-450404015514
U301: BU33SD5WG-TR; SOT-23-5
U302: WE-TVS-82400102; SOT-23-6

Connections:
+3.3V: C302.1, U301.5 (OUT); also elsewhere on the board
+5V: C303.1, C304.1, IC301.6 (VCC), J302.A4 (VBUS), J302.A9 (VBUS), J302.B4 (VBUS), J302.B9 (VBUS), U302.5
+BATT: C301.1, S301.1, U301.1 (IN), U301.3 (STBY); also elsewhere on the board
/POWER/BAT: IC301.1 (BSENSE), IC301.2 (BAT), J301.1, S301.2; also elsewhere on the board
/POWER/USB_DM: U302.6; also elsewhere on the board
/POWER/USB_DP: U302.4; also elsewhere on the board
GND: C301.2, C302.2, C303.2, C304.2, IC301.4 (GND), IC301.9 (EP), J301.2, J302.A1 (GND), J302.A12 (GND), J302.B1 (GND), J302.B12 (GND), J302.S1 (SHIELD), R301.2, R302.2, R303.1, S301.MP1, S301.MP2, S301.MP3, S301.MP4, U301.2 (GND), U302.2; also elsewhere on the board
unnamed: IC301.5 (PROG), R301.1
unnamed: J302.A5 (CC1), R302.1
unnamed: J302.B5 (CC2), R303.2
unnamed: J302.A6 (D+), J302.B6 (D+), U302.3
unnamed: J302.A7 (D-), J302.B7 (D-), U302.1

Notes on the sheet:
Chargeur de batterie
USB C
Régulateur de tension du TOF et du moteur
Switch

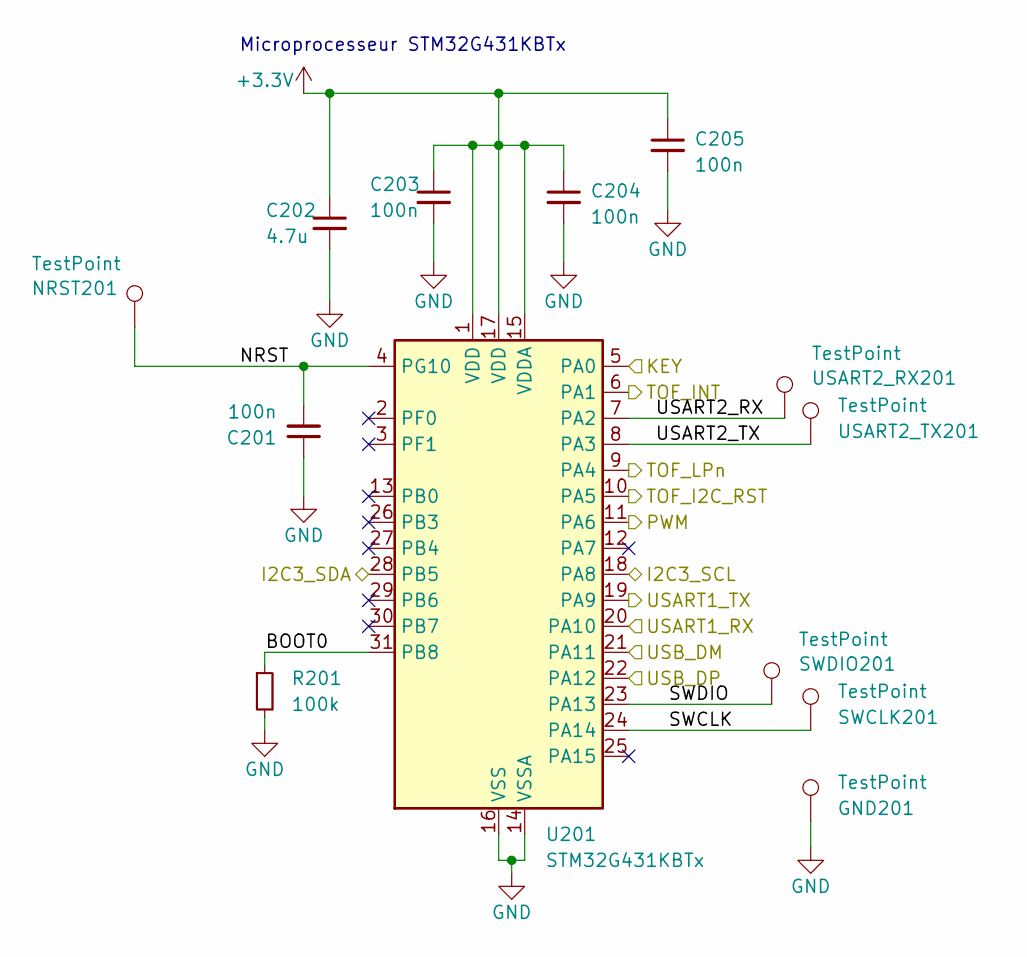
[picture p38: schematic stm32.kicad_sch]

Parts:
C201, C203, C204, C205: 100n; C_0402_1005Metric
C202: 4.7u; C_0402_1005Metric
GND201: TestPoint; TestPoint_Pad_D1.0mm
NRST201: TestPoint; TestPoint_Pad_D1.0mm
R201: 100k; R_0402_1005Metric
SWCLK201: TestPoint; TestPoint_Pad_D1.0mm
SWDIO201: TestPoint; TestPoint_Pad_D1.0mm
U201: STM32G431KBTx; LQFP-32_7x7mm_P0.8mm
USART2_RX201, USART2_TX201: TestPoint; TestPoint_Pad_D1.0mm

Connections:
+3.3V: C202.1, C203.1, C204.1, C205.1, U201.1 (VDD), U201.15 (VDDA), U201.17 (VDD); also elsewhere on the board
/BLUETOOTH/KEY: U201.5 (PA0); also elsewhere on the board
/BLUETOOTH/USART1_RX: U201.19 (PA9); also elsewhere on the board
/BLUETOOTH/USART1_TX: U201.20 (PA10); also elsewhere on the board
/MOTOR/PWM: U201.11 (PA6); also elsewhere on the board
/POWER/USB_DM: U201.21 (PA11); also elsewhere on the board
/POWER/USB_DP: U201.22 (PA12); also elsewhere on the board
/SENSORS/I2C3_SCL: U201.18 (PA8); also elsewhere on the board
/SENSORS/I2C3_SDA: U201.28 (PB5); also elsewhere on the board
/SENSORS/TOF_I2C_RST: U201.10 (PA5); also elsewhere on the board
/SENSORS/TOF_INT: U201.6 (PA1); also elsewhere on the board
/SENSORS/TOF_LPn: U201.9 (PA4); also elsewhere on the board
/STM32/BOOT0: R201.1, U201.31 (PB8)
/STM32/NRST: C201.2, NRST201.1, U201.4 (PG10)
/STM32/SWCLK: SWCLK201.1, U201.24 (PA14)
/STM32/SWDIO: SWDIO201.1, U201.23 (PA13)
/STM32/USART2_RX: U201.7 (PA2), USART2_RX201.1
/STM32/USART2_TX: U201.8 (PA3), USART2_TX201.1
GND: C201.1, C202.2, C203.2, C204.2, C205.2, GND201.1, R201.2, U201.14 (VSSA), U201.16 (VSS), U201.32 (VSS); also elsewhere on the board

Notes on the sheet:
Microprocesseur STM32G431KBTx

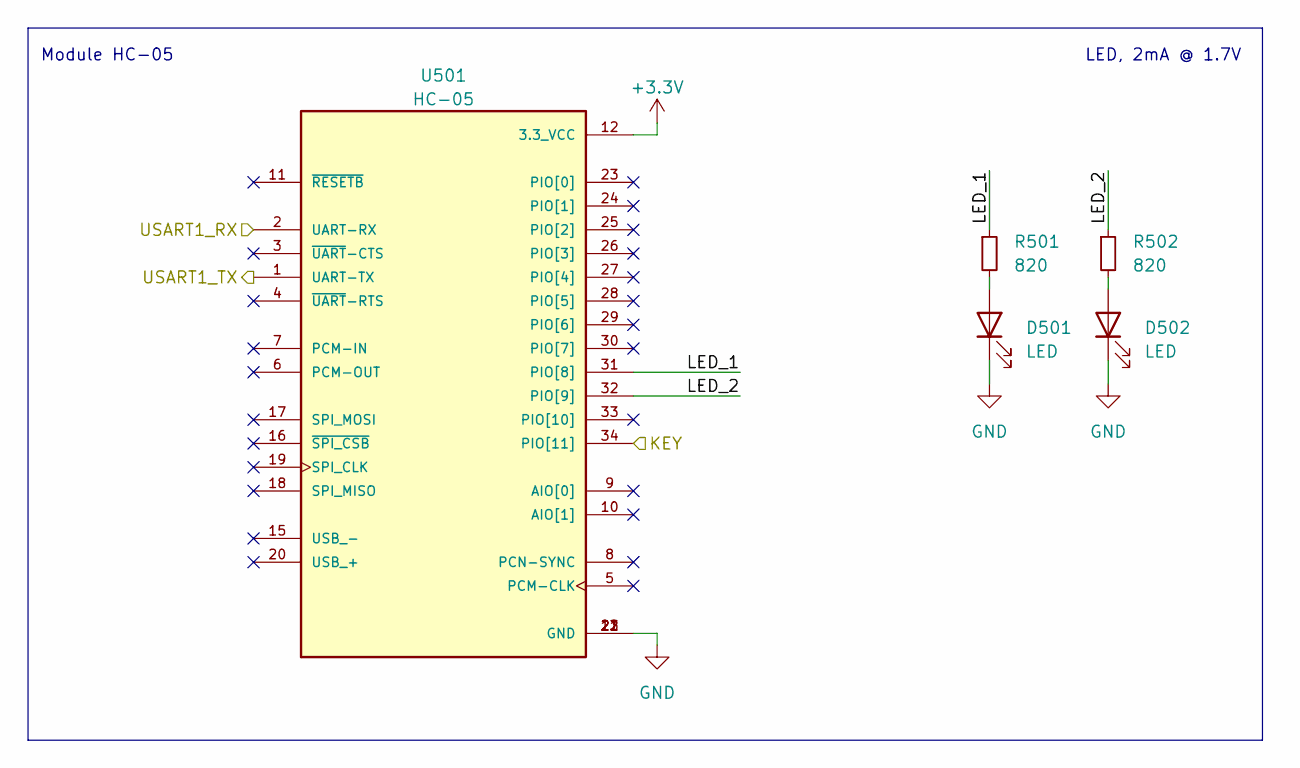
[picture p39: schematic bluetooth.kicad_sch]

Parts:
D501, D502: LED; LED_0603_1608Metric
R501, R502: 820; R_0402_1005Metric
U501: HC-05; XCVR_HC-05; PARTREV v1.0

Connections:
+3.3V: U501.12 (3.3_VCC); also elsewhere on the board
/BLUETOOTH/KEY: U501.34 (PIO[11]); also elsewhere on the board
/BLUETOOTH/LED_1: R501.1, U501.31 (PIO[8])
/BLUETOOTH/LED_2: R502.1, U501.32 (PIO[9])
/BLUETOOTH/USART1_RX: U501.2 (UART-RX); also elsewhere on the board
/BLUETOOTH/USART1_TX: U501.1 (UART-TX); also elsewhere on the board
GND: D501.1 (K), D502.1 (K), U501.13 (GND), U501.21 (GND), U501.22 (GND); also elsewhere on the board
unnamed: D501.2 (A), R501.2
unnamed: D502.2 (A), R502.2

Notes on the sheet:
LED, 2mA @ 1.7V
Module HC-05

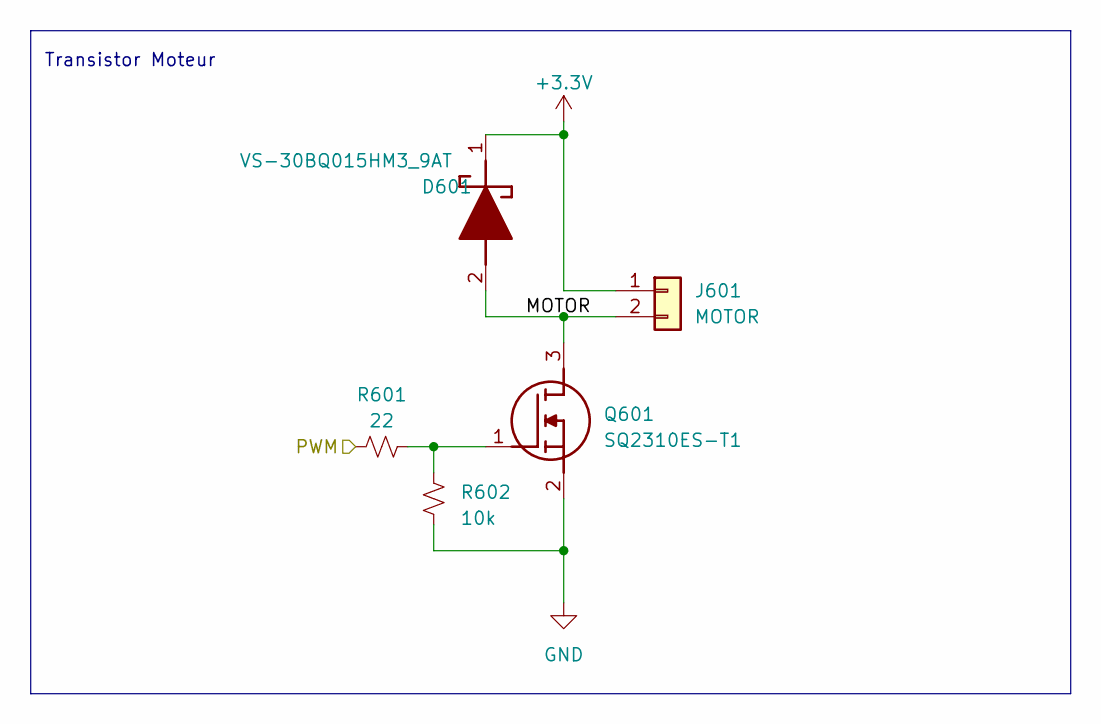
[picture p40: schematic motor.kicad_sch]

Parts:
D601: VS-30BQ015HM3_9AT; DIOM7959X262N; Manufacturer_Part_Number VS-30BQ015HM3/9AT; Mouser Part Number 78-VS-30BQ015HM39AT
J601: MOTOR; PinHeader_1x02_P1.27mm_Vertical
Q601: SQ2310ES-T1; SOT95P237X112-3N; Manufacturer_Part_Number SQ2310ES-T1
R601: 22; R_0402_1005Metric
R602: 10k; R_0402_1005Metric

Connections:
+3.3V: D601.1 (K), J601.1; also elsewhere on the board
/MOTOR/MOTOR: D601.2 (A), J601.2, Q601.3 (D)
/MOTOR/PWM: R601.1; also elsewhere on the board
GND: Q601.2 (S), R602.2; also elsewhere on the board
unnamed: Q601.1 (G), R601.2, R602.1

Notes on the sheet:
Transistor Moteur

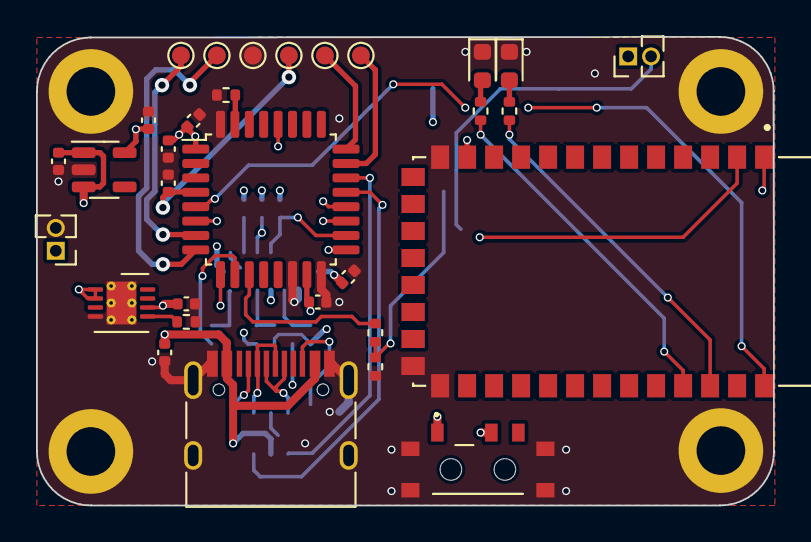
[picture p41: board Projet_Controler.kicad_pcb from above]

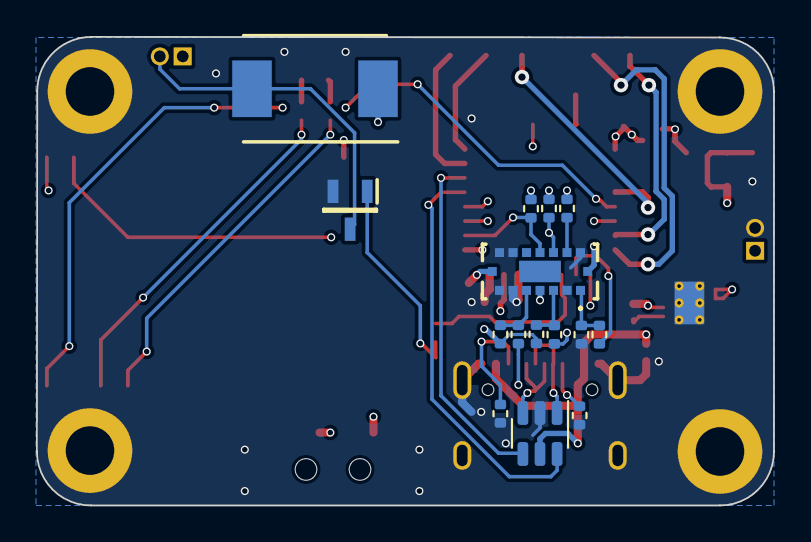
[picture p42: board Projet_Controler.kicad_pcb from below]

Board: 4 copper layers, 41.0 x 26.0 mm, 50 parts (15 on the bottom side), 37 nets.

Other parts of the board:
IC**: VL53L5CX
S**: 450404015514

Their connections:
+3.3V: IC**.A4, IC**.B1, IC**.B7; also elsewhere on the board
+BATT: S**.1; also elsewhere on the board
/POWER/BAT: S**.2; also elsewhere on the board
/SENSORS/I2C3_SCL: IC**.C4; also elsewhere on the board
/SENSORS/I2C3_SDA: IC**.C3; also elsewhere on the board
GND: IC**.A2, IC**.A6, IC**.A7, IC**.C1, IC**.C6, IC**.C7, S**.MP1, S**.MP2, S**.MP3, S**.MP4; also elsewhere on the board
unnamed 28: IC**.A1; also elsewhere on the board
unnamed 29: IC**.A3; also elsewhere on the board
unnamed 30: IC**.A5; also elsewhere on the board
unnamed 31: IC**.C2; also elsewhere on the board

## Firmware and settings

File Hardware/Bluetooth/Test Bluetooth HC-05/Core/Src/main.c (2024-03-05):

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
/* Includes ------------------------------------------------------------------*/
#include "main.h"

UART_HandleTypeDef huart1;

/* USER CODE BEGIN PV */
uint8_t rxData;
uint8_t txData[] = {76,69,71,79,33,33,33,33,10}; // Code ASCII de "LEGO!!!!"
/* USER CODE END PV */

void SystemClock_Config(void);
static void MX_GPIO_Init(void);
static void MX_USART1_UART_Init(void);
/**
  * @brief  The application entry point.
  * @retval int
  */
int main(void)
{
  /* MCU Configuration--------------------------------------------------------*/

  /* Reset of all peripherals, Initializes the Flash interface and the Systick. */
  HAL_Init();

  /* Configure the system clock */
  SystemClock_Config();

  /* Initialize all configured peripherals */
  MX_GPIO_Init();
  MX_USART1_UART_Init();
  /* USER CODE BEGIN 2 */
  HAL_UART_Receive_IT(&huart1,&rxData,1);
  /* USER CODE END 2 */

  /* Infinite loop */
  /* USER CODE BEGIN WHILE */
  while (1)
  {
    /* USER CODE END WHILE */

    /* USER CODE BEGIN 3 */

	  if ( HAL_GPIO_ReadPin(GPIOC,GPIO_PIN_13) == 0)
	  {
		  HAL_UART_Transmit(&huart1,txData,sizeof(txData),HAL_MAX_DELAY);
		  HAL_Delay(100);
	  }

  }
  /* USER CODE END 3 */
}

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
/* USER CODE BEGIN 4 */
void HAL_UART_RxCpltCallback(UART_HandleTypeDef *huart)
{
  if(huart->Instance==USART1)
  {
    if(rxData==79) // Ascii value of 'O' is 79
    {
    	HAL_GPIO_WritePin(GPIOA, GPIO_PIN_5, 1);
    }
    else if (rxData==88) // Ascii value of 'X' is 88
    {
    	HAL_GPIO_WritePin(GPIOA, GPIO_PIN_5, 0);
    }
    HAL_UART_Receive_IT(&huart1,&rxData,1); // Enabling interrupt receive again
  }
}
/* USER CODE END 4 */
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


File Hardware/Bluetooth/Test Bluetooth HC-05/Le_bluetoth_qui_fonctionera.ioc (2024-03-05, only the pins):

Mcu.UserName=STM32L476RGTx
PA10.Signal=USART1_RX
PA2.GPIO_Label=USART_TX
PA2.Signal=USART2_TX
PA3.GPIO_Label=USART_RX
PA3.Signal=USART2_RX
PA5.GPIO_Label=LD2 [green Led]
PA5.Signal=GPIO_Output
PA9.Signal=USART1_TX
PC13.GPIO_Label=B1 [Blue PushButton]
PC13.Signal=GPXTI13

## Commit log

2023-10-10 resources
    Nucleo board and TOF resources
2023-10-10 Add resources
    Interesting links to program I2C
2023-10-10 I2C sources
2023-10-17 updated the menu (added the quit button)
2023-12-05 fixing quit button in pause menu
2023-12-05 Diapo + Structure
    [TOF_pin.xlsx, composants_principaux.xlsx, pins_microcontroller.xlsx]
2023-12-05 Bluetooth
    Creation du dossier Bluetooth et ajout de documentation
2023-12-19 fixed quit button
2024-01-16 game.py correction and pipe + collision inserted
2024-03-05 Ajout du projet STM32 du test blutooth HC-05
2024-03-05 TOF Updates
    [TOF_Pin.xlsx]
2024-03-05 update pcb
    [Projet_Controler.kicad_pcb, Projet_Controler.kicad_sch, bluetooth.kicad_sch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]
2024-03-19 PCB V4
    [Projet_Controler.kicad_pcb, Projet_Controler.kicad_sch, bluetooth.kicad_sch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]
2024-03-19 reroutage LF pas assumé à 100%
    [Projet_Controler.kicad_sch, bluetooth.kicad_sch, motor.kicad_sch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]
2024-03-26 PCB V5
    [Projet_Controler.kicad_pcb, Projet_Controler.kicad_sch, bluetooth.kicad_sch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]
2024-03-26 add gnd via
    [Projet_Controler.kicad_pcb]
2024-03-26 Supports 3D
    [Manette-Moteur.stl, Manette_Base.stl, Manette_PCB.stl]

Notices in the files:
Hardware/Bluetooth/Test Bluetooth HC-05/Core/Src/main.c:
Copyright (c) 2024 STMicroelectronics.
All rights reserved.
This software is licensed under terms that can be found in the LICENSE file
